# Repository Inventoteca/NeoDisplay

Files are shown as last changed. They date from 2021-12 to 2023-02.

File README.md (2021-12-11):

# NeoDisplay
This repository is a colection of displays made with NeoDigitos.  
The NeoDigito library for Arduino is [here](https://github.com/Inventoteca/NeoDigito)

## NeoClock - Internet Clock, Weather & IoT Panel
NeoClock is a clock connected to the Internet, that in addition to show time and date,
can be configured to show other data, as weather and messages sent from a remote
device whithout extra hardware.  

It's build with 4 NeoDigitos.  

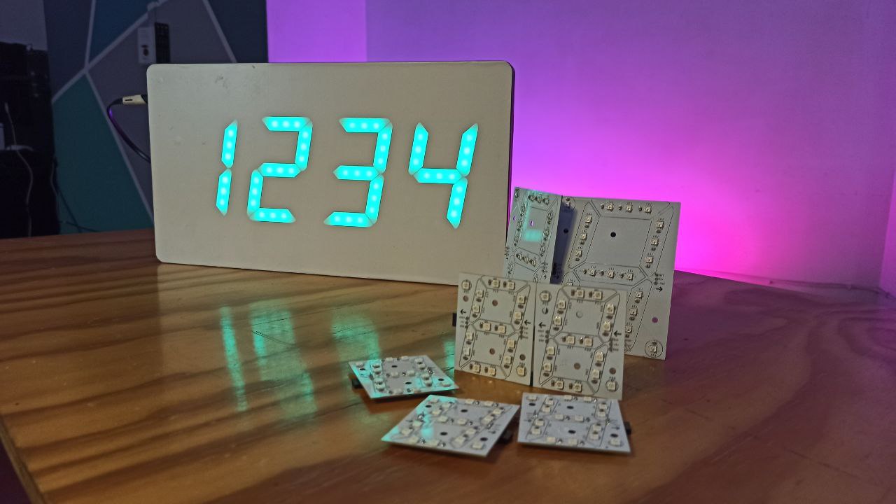
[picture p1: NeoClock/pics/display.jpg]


## Single Digit
This display uses one single digit  

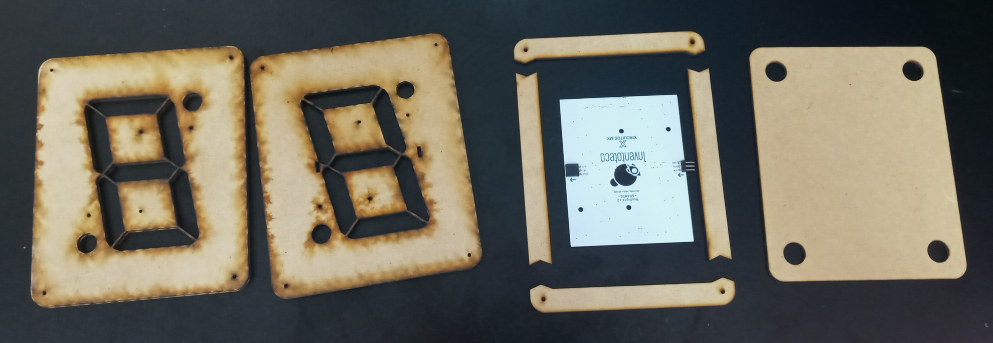
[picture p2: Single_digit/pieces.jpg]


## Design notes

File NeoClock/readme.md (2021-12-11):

# NeoClock - Internet Clock, Weather & IoT Panel

NeoClock is a clock connected to the Internet, that in addition to show time and date,
can be configured to show other data, as weather and messages sent from a remote device
whithout extra hardware.  

It's build with 4 NeoDigitos.  

- **pics** - photos and diagrams
- **eagle** - test pcb design for ESP-01
- **cad** - 3D model and drawings for laser cut

Archivos de esquematico y placa en Eagle para el diseño de pcb,
para poder alimentar y reprogramar ESP 01 sin necesidad de extraer la tapa.

El circuito consta de un convertidor de micro USB a serial, un ESP 01, 2 botones y pines machos y hembras,
es importante tomar en cuenta el diseño del display para el orden y dimenciones del circuito

La primera versión consta de una placa perforada para circuito, sin embargo el tamaño tan ancho no permitia
que este se pudiera cerrar.
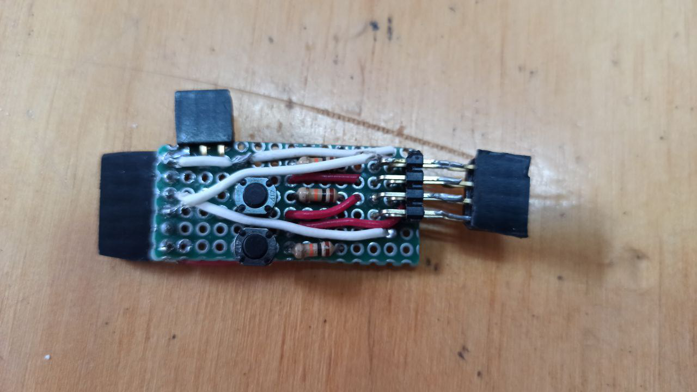
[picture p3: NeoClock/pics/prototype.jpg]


La segunda versión fue rediseñada en Eagle para realizarse en router para pcb de esta manera se puede ahorrar espacio,
lo que nos permite que el display no sea tan ancho, dando como resultado un diseño mas compacto.
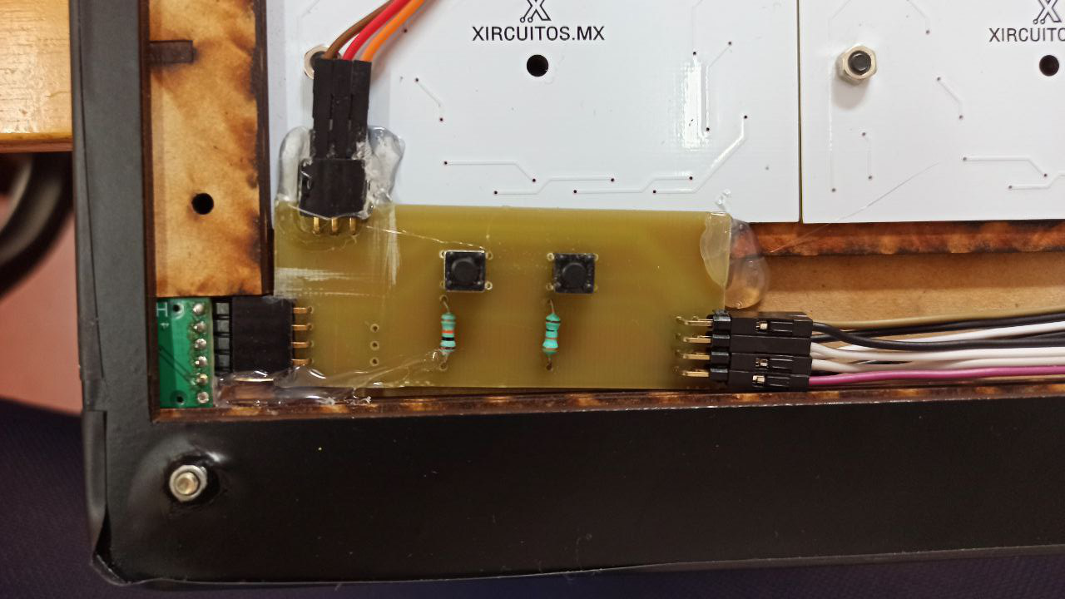
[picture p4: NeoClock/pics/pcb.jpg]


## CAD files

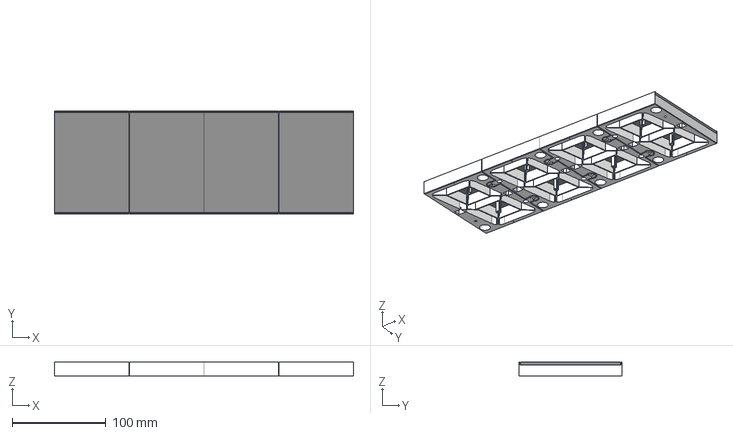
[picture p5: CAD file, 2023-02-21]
NeoClock/cad/NeoClock Big - single diffuser.step
319.8 x 110.0 x 15.5 mm
Difusor
Separador

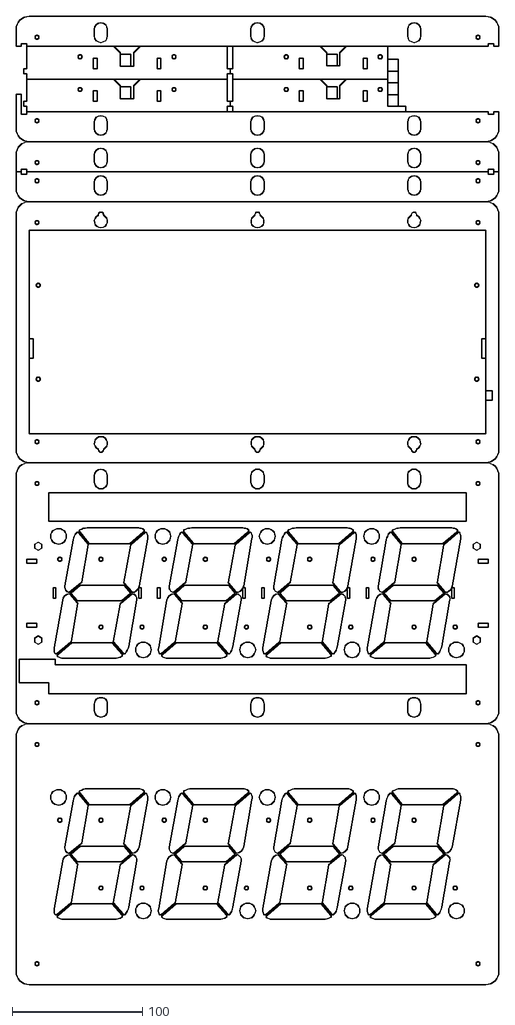
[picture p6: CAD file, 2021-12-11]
NeoClock/cad/neoclock_wemos_mdf3mm_370x742.dxf
370.0 x 742.0

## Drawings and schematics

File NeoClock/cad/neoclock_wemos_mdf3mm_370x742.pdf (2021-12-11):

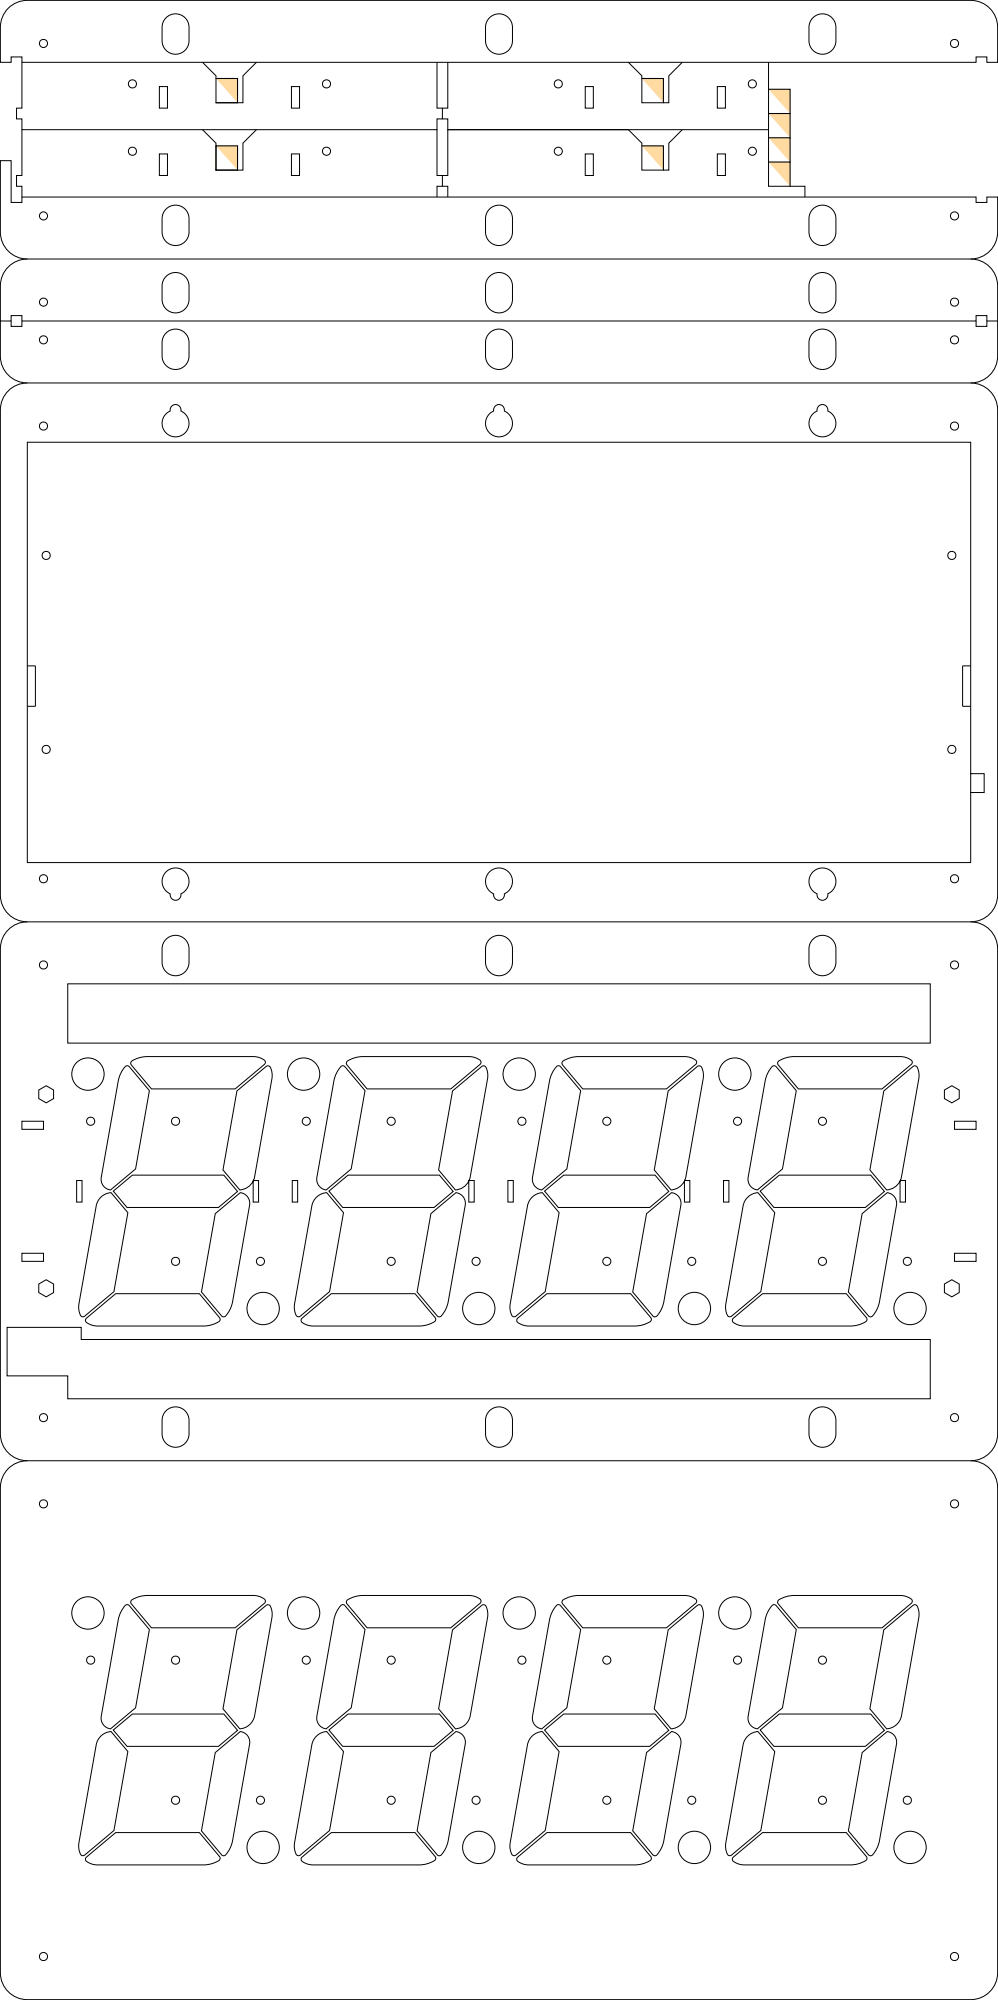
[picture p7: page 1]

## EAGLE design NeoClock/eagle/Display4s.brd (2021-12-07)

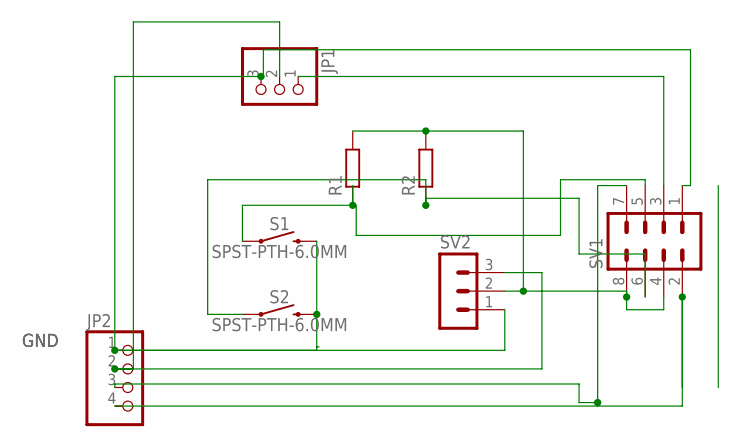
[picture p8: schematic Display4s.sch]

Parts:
JP1: PINHD-1X3; 1X03
JP2: PINHD-1X4; 1X04
R1, R2: R-EU_0207/10; 0207/10
S1, S2: SPST-PTH-6.0MM; TACTILE_SWITCH_PTH_6.0MM
SV1: MA04-2
SV2: MA03-1

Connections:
3V3: R1.2, R2.2, SV1.4, SV1.8, SV2.2
5V: JP1.2, JP2.2, SV2.3
FLASH: R1.1, S1.1, SV1.5
GND: JP1.3, JP2.1, S1.3 (2), S2.3 (2), SV1.1, SV2.1
RESET: R2.1, S2.1, SV1.6
RX: JP2.3, SV1.7
SING: JP1.1, SV1.3
TX: JP2.4, SV1.2

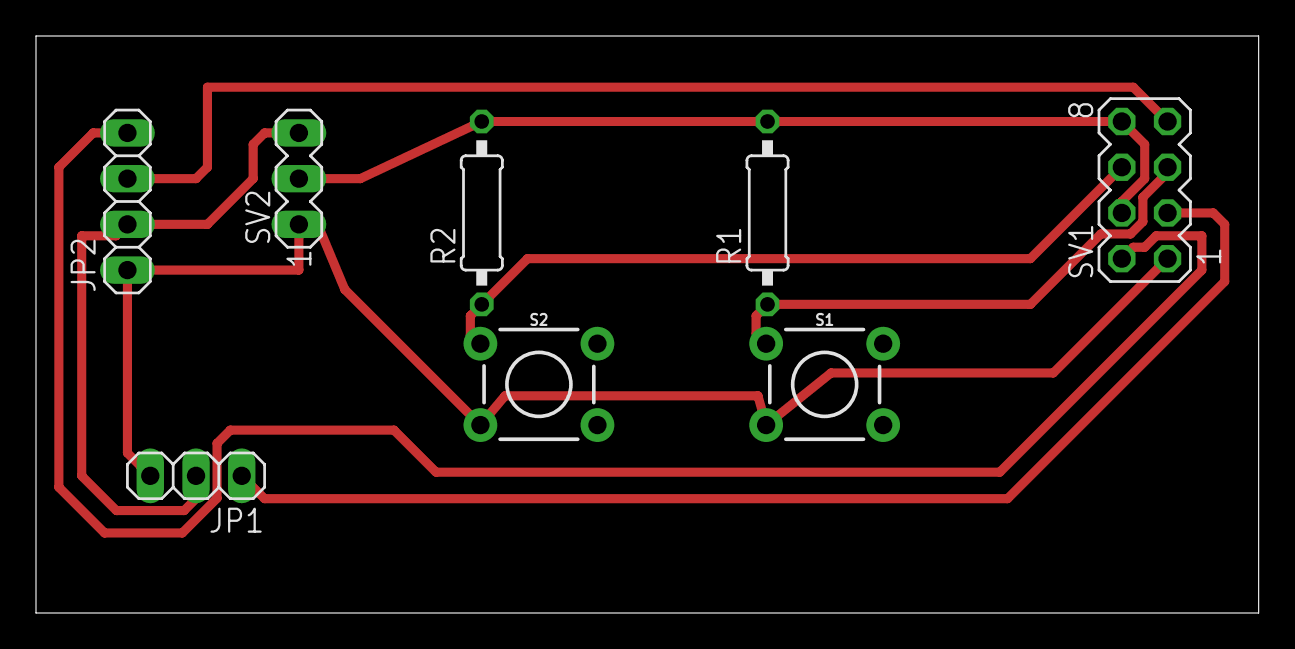
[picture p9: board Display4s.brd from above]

Board: 2 copper layers, 67.9 x 32.1 mm, 8 parts (0 on the bottom side), 8 nets.

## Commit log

2021-12-11 move display files to folder
    [Display4s.brd, Display4s.sch]
2021-12-11 rename folder
    [Display4s.brd, Display4s.sch]
2021-12-11 create sub-folders
    [Display4s.brd, Display4s.sch, neoclock_wemos_mdf3mm_370x742.dxf]

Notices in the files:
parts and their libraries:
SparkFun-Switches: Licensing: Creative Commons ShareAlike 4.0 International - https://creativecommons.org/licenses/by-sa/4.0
